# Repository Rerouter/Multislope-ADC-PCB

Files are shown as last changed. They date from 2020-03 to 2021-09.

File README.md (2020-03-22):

# Multislope-ADC-PCB
High Resolution Multi-slope ADC Kicad Files

Based on Kleinsteins original design as discussed on the EEVBlog Forum

https://www.eevblog.com/forum/metrology/diy-high-resolution-multi-slope-converter/

https://www.eevblog.com/forum/projects/multislope-design/

The goal of the project is to create a low cost multislope ADC with a useable resolution of 6.5 digits or higher.

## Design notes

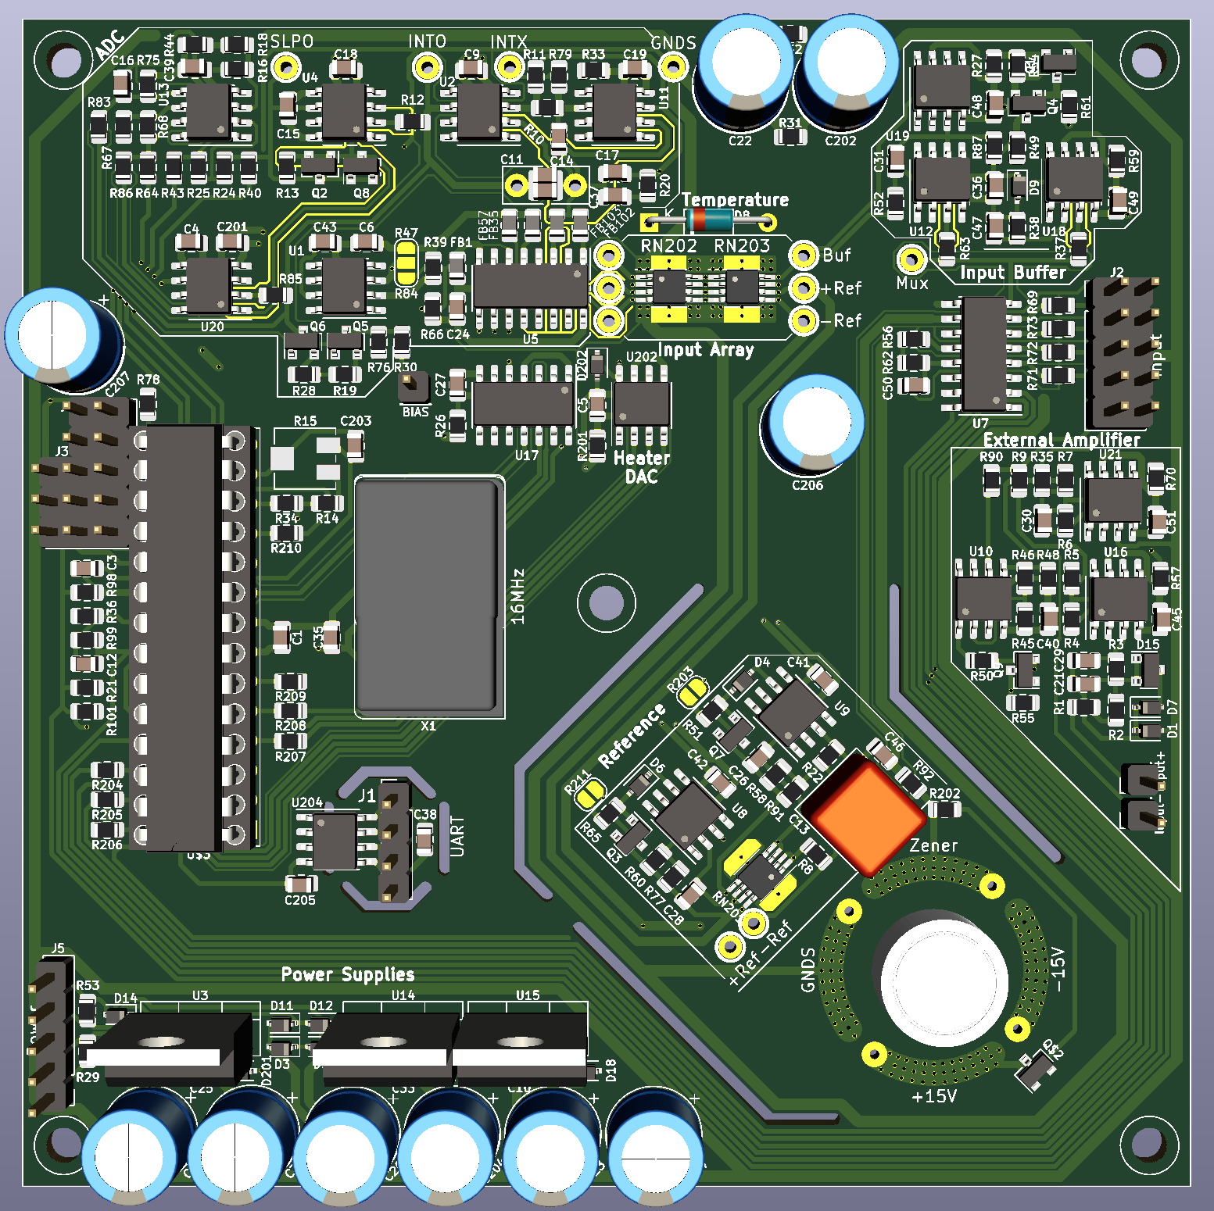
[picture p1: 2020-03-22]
ADC rev2-8.PNG

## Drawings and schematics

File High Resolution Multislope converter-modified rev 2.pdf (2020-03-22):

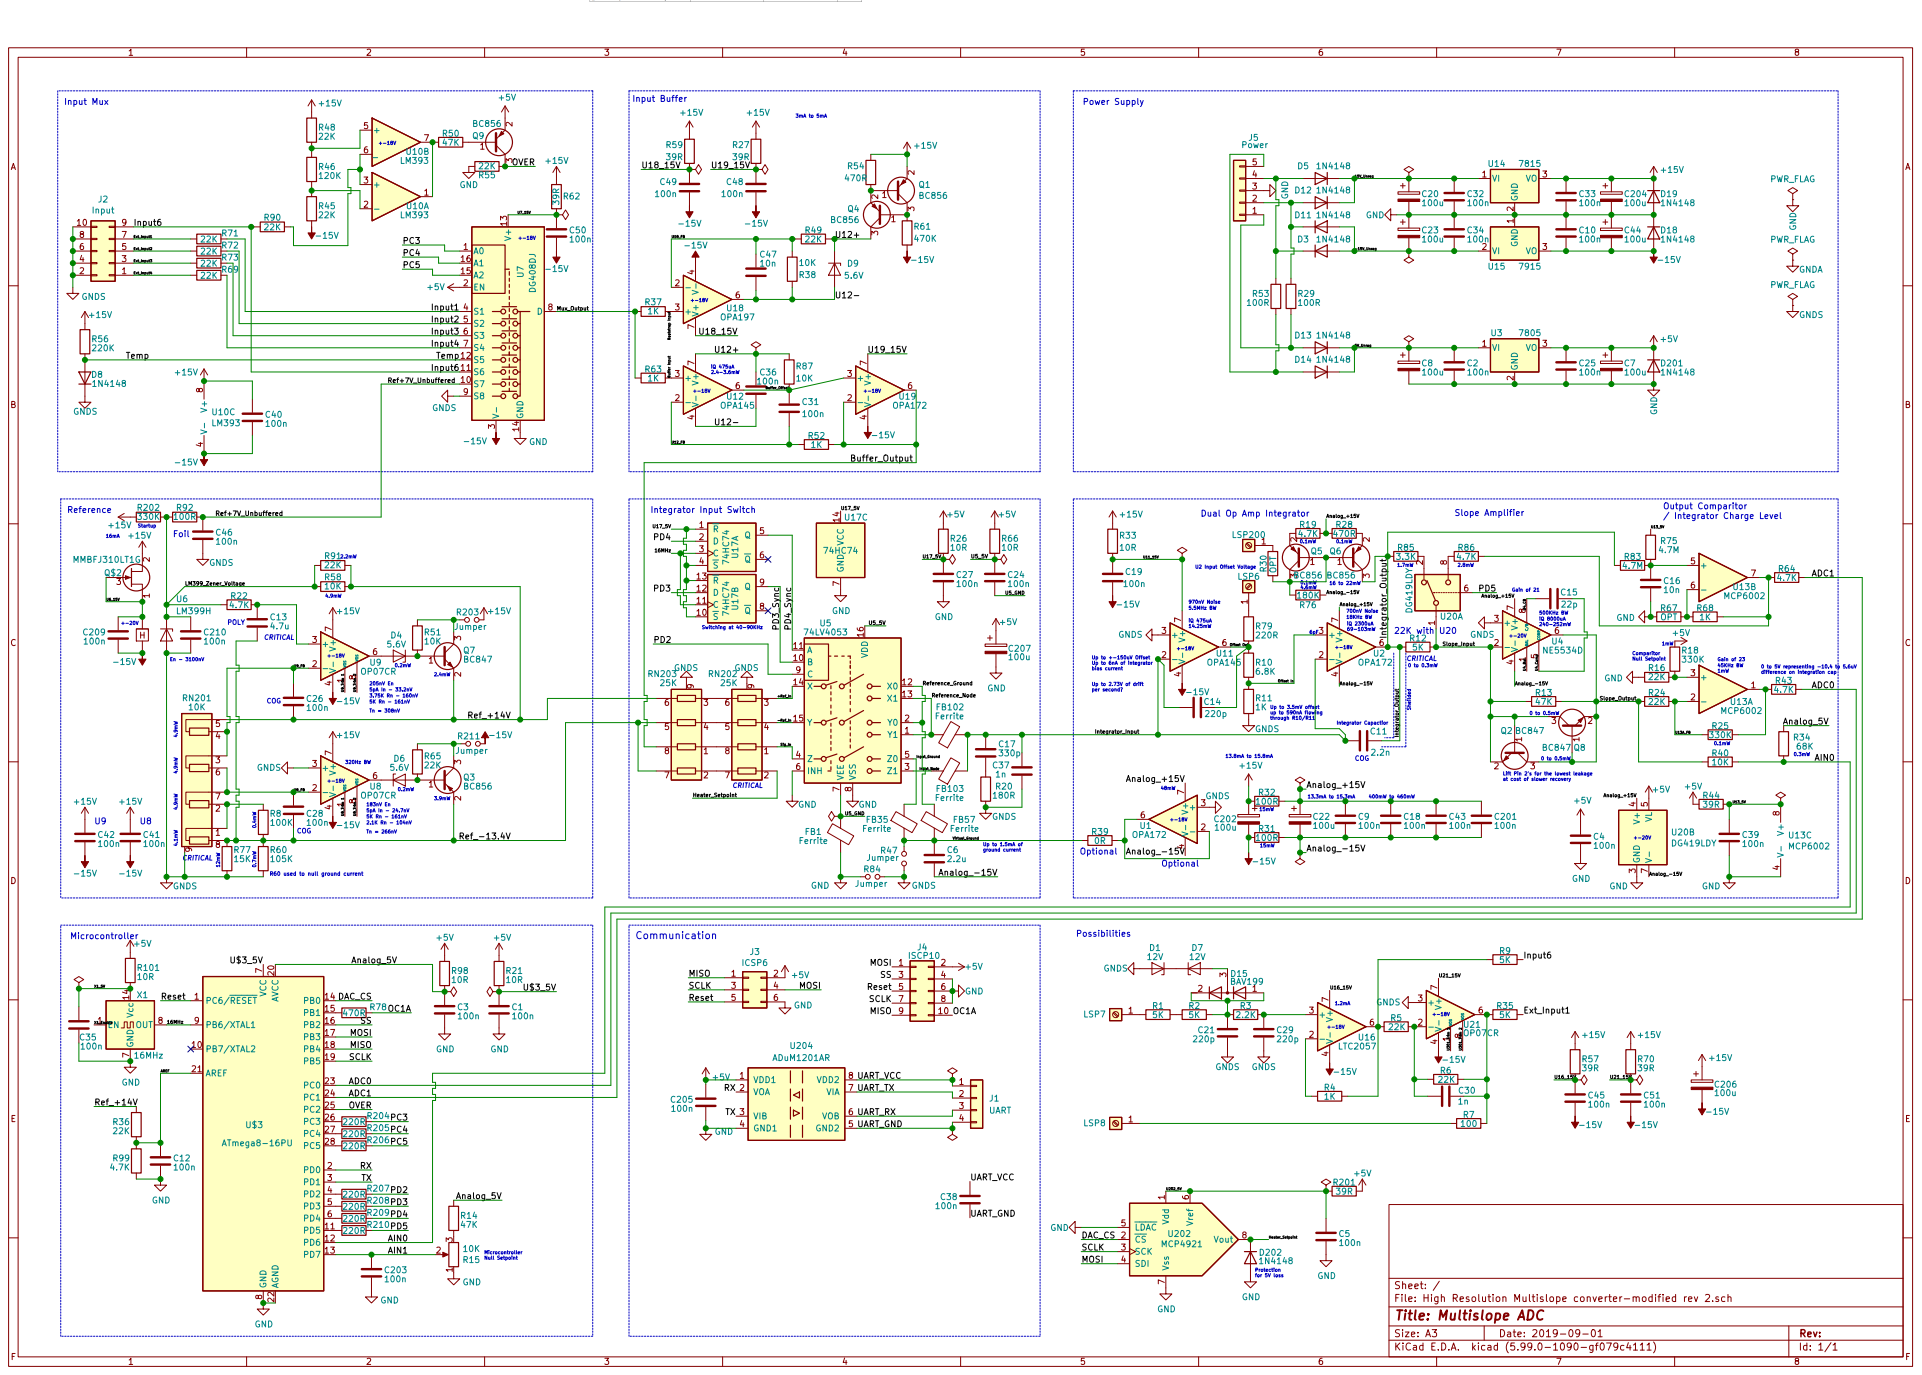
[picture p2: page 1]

U5_5V Bootstrap Input Buffer Input

/ Integrator Charge Level Switching at 40-90KHz COG

700nV Noise U2 Input Offset Voltage

Comparitor Null Setpoint 5pA In - 24.7nV

Lift Pin 2's for the lowest leakage

48mW Optional +-18V Up to 1.5mA of ground current

R60 used to null ground current 4.9mW 4.1mW

File: High Resolution Multislope converter-modified rev 2.sch Sheet: /
Id: 1/1 Title: Multislope ADC

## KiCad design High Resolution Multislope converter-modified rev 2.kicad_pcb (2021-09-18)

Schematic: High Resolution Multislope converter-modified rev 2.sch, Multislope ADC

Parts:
C1, C2, C3, C4, C5, C9, C10, C12, C18, C19, C24, C25, C26, C27, C28, C31, C32, C33, C34, C35, C36, C38, C39, C40, C41, C42, C43, C45, C46, C48, C49, C50, C51, C201, C203, C205, C209, C210: 100n; C_0805_2012Metric
C6: 2.2u; C_0805_2012Metric
C7, C8, C20, C22, C23, C44, C202, C204, C206, C207: 100u; CP_Radial_D8.0mm_P3.50mm
C11: 2.2n; C_Rect_L7.2mm_W3.0mm_P5.00mm_FKS2_FKP2_MKS2_MKP2
C13: 4.7u; C_Rect_L7.2mm_W7.2mm_P5.00mm_FKS2_FKP2_MKS2_MKP2
C14, C21, C29: 220p; C_0805_2012Metric
C15: 22p; C_0805_2012Metric
C16, C47: 10n; C_0805_2012Metric
C17: 330p; C_0805_2012Metric
C30, C37: 1n; C_0805_2012Metric
D1, D7: 12V; D_SOD-323
D3, D5, D8, D11, D12, D13, D14, D18, D19, D201, D202: 1N4148; D_SOD-323
D4, D6, D9: 5.6V; D_SOD-323
D15: BAV199; SOT-23; Manufacturer PArt Number BAV199-7-F; Digikey Part Number BAV199-FDICT-ND
FB1, FB35, FB57, FB102, FB103: Ferrite; L_0805_2012Metric; Manufacturer PArt Number MMZ2012Y152BT
J1: UART; PinHeader_1x04_P2.54mm_Vertical
J2: Input; PinHeader_2x05_P2.54mm_Vertical
J3: ICSP6; PinHeader_2x03_P2.54mm_Vertical
J4: ISCP10; PinHeader_2x05_P2.54mm_Vertical
J5: Power; PinHeader_1x05_P2.54mm_Vertical
LSP6: INTX; PinHeader_1x01_P2.54mm_Vertical
LSP7: Input+; PinHeader_1x01_P2.54mm_Vertical
LSP8: Input-; PinHeader_1x01_P2.54mm_Vertical
LSP200: BIAS; PinHeader_1x01_P2.54mm_Vertical
Q1, Q3, Q4, Q5, Q6, Q9: BC856; SOT-23; Manufacturer PArt Number BC857CLT1G
Q2, Q7, Q8: BC847; SOT-23; Manufacturer PArt Number BC847BLT3G
Q$2: MMBFJ310LT1G; SOT-23; Manufacturer PArt Number MMBFJ310LT1G
R1, R2, R9, R12, R35: 5K; R_0805_2012Metric
R3: 2.2K; R_0805_2012Metric
R4, R11, R37, R52, R63, R68: 1K; R_0805_2012Metric
R5, R6, R16, R24, R36, R45, R48, R49, R55, R65, R69, R71, R72, R73, R90, R91: 22K; R_0805_2012Metric
R7: 100; R_0805_2012Metric
R8: 100K; R_0805_2012Metric
R10: 6.8K; R_0805_2012Metric
R13, R14, R50: 47K; R_0805_2012Metric
R15: 10K; Potentiometer_Vishay_TS53YJ_Vertical
R18, R25, R202: 330K; R_0805_2012Metric
R19, R22, R43, R64, R86, R99: 4.7K; R_0805_2012Metric
R20: 180R; R_0805_2012Metric
R21, R26, R33, R66, R98, R101: 10R; R_0805_2012Metric
R27, R44, R57, R59, R62, R70, R201: 39R; R_0805_2012Metric
R28, R54, R78: 470R; R_0805_2012Metric
R29, R31, R32, R53, R92: 100R; R_0805_2012Metric
R30, R67: OPT; R_0805_2012Metric
R34: 68K; R_0805_2012Metric
R38, R40, R51, R58, R87: 10K; R_0805_2012Metric
R39: 0R; R_0805_2012Metric
R46: 120K; R_0805_2012Metric
R47, R84, R203, R211: Jumper; SolderJumper-2_P1.3mm_Open_RoundedPad1.0x1.5mm
R56: 220K; R_0805_2012Metric
R60: 105K; R_0805_2012Metric
R61: 470K; R_0805_2012Metric
R75, R83: 4.7M; R_0805_2012Metric
R76: 180K; R_0805_2012Metric
R77: 15K; R_0805_2012Metric
R79, R204, R205, R206, R207, R208, R209, R210: 220R; R_0805_2012Metric
R85: 3.3K; R_0805_2012Metric
RN201: 10K; MSOP-8-1EP_3x3mm_P0.65mm_EP1.73x1.85mm
RN202, RN203: 25K; MSOP-8-1EP_3x3mm_P0.65mm_EP1.73x1.85mm
U1, U2, U19: OPA172; SOIC-8_3.9x4.9mm_P1.27mm
U3: 7805; TO-220-3_Vertical
U4: NE5534D; SOIC-8_3.9x4.9mm_P1.27mm; Manufacturer PArt Number NE5534ADR2
U5: 74LV4053; SOIC-16_3.9x9.9mm_P1.27mm
U6: LM399H; TO-46-4; Manufacturer PArt Number LM399H#PBF
U7: DG408DJ; SOIC-16_3.9x9.9mm_P1.27mm; Manufacturer PArt Number DG408DY-T1-E3
U8, U9, U21: OP07CR; SOIC-8_3.9x4.9mm_P1.27mm
U10: LM393; SOIC-8_3.9x4.9mm_P1.27mm; Manufacturer PArt Number LM393DR2G
U11, U12: OPA145; SOIC-8_3.9x4.9mm_P1.27mm
U13: MCP6002; SOIC-8_3.9x4.9mm_P1.27mm; Manufacturer PArt Number MCP6002-E/SN
U14: 7815; TO-220-3_Vertical; Manufacturer PArt Number MC7815ACTG
U15: 7915; TO-220-3_Vertical; Manufacturer PArt Number MC7915CTG
U16: LTC2057; SOIC-8_3.9x4.9mm_P1.27mm; Manufacturer PArt Number LTC2057IS8#PBF
U17: 74HC74; SOIC-14_3.9x8.7mm_P1.27mm
U18: OPA197; SOIC-8_3.9x4.9mm_P1.27mm
U20: DG419LDY; SOIC-8_3.9x4.9mm_P1.27mm; Manufacturer PArt Number DG419DY-E3
U202: MCP4921; SOIC-8_3.9x4.9mm_P1.27mm; Manufacturer PArt Number MCP4821-E/SN
U204: ADuM1201AR; SOIC-8_3.9x4.9mm_P1.27mm; Manufacturer PArt Number ADUM1201ARZ
U$3: ATmega8-16PU; DIP-28_W7.62mm_Socket_LongPads
X1: 16MHz; Oscillator_DIP-14

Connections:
+5V: C4.1, C7.1, C25.1, C205.1, C207.1, D201.1 (K), J3.2, J4.2, Q9.2 (E), R18.1, R21.1, R26.1, R44.2, R66.1, R98.1, R101.1, R201.1, U3.3 (VO), U7.2 (EN), U20.5 (VL), U204.1 (VDD1)
+15V: C33.1, C40.1, C41.1, C42.1, C202.1, C204.1, C206.1, D19.1 (K), Q1.2 (E), Q$2.2 (S), R27.2, R32.2, R33.1, R48.1, R54.2, R56.1, R57.1, R59.2, R62.2, R70.1, R202.2, R203.2, U8.7 (V+), U9.7 (V+), U10.8, U14.3
-15V: C10.2, C19.2, C40.2, C41.2, C42.2, C44.2, C45.2, C48.2, C49.2, C50.2, C51.2, C202.2, C206.2, C209.2, D18.2 (A), R31.2, R45.2, R61.1, R211.2, U6.4 (-), U7.3 (V-), U8.4 (V-), U9.4 (V-), U10.4, U11.4 (V-), U15.3, U16.4 (V-), U18.4 (V-), U19.4 (V-), U21.4 (V-)
/5V_Unreg: C2.1, C8.1, D13.1 (K), D14.1 (K), U3.1 (VI)
/15V_Unreg: C20.1, C32.1, D5.1 (K), D12.1 (K), U14.1
/16MHz: U17.3 (C), U17.11 (C), U$3.9 (PB6/XTAL1), X1.8 (OUT)
/+Ref_In: RN202.3 (R3.1), U5.14 (X); also elsewhere on the board
/-15V_Unreg: C23.2, C34.2, D3.2 (A), D11.2 (A), U15.2
/-Ref_In: RN202.4 (R4.1), U5.15 (Y); also elsewhere on the board
/ADC0: R43.1, U$3.23 (PC0)
/ADC1: R64.1, U$3.24 (PC1)
/AIN0: R34.1, R40.1, U$3.12 (PD6)
/AIN1: C203.1, R15.2, U$3.13 (PD7)
/AREF: C12.1, R36.2, R99.1, U$3.21 (AREF)
/Analog_5V: C3.1, R14.1, R34.2, R98.2, U$3.20 (AVCC)
/Analog_+15V: C9.1, C18.1, C22.1, C43.1, C201.1, R19.1, R28.1, R32.1, U1.7 (V+), U2.7 (V+), U4.7 (V+), U20.4 (V+)
/Analog_-15V: C6.2, C9.2, C18.2, C22.2, C43.2, C201.2, R31.1, R76.2, U1.4 (V-), U2.4 (V-), U4.4 (V-), U20.7 (V-)
/Bootstrap Input: R37.1, U18.3 (+)
/Buffer Input: R63.1, U12.3 (+)
/Buffer_Offset: C31.2, R87.2, U12.6, U19.3 (+)
/Buffer_Output: R52.1, RN203.8 (R1.2), U19.2 (-), U19.6; also elsewhere on the board
/DAC_CS: U202.2 (~CS), U$3.14 (PB0)
/Ext_Input1: J2.7, R35.1, R71.2
/Ext_Input2: J2.5, R72.2
/Ext_Input3: J2.3, R73.2
/Ext_Input4: J2.1, R69.2
/Heater_Setpoint: D202.1 (K), RN202.2 (R2.1), U202.8 (Vout); also elsewhere on the board
/Input1: R71.1, U7.4 (S1)
/Input2: R72.1, U7.5 (S2)
/Input3: R73.1, U7.6 (S3)
/Input4: R69.1, U7.7 (S4)
/Input6: J2.9, R9.1, R90.2, U7.11 (S6)
/Input_Ground: FB35.1, U5.5 (Z0)
/Input_Node: FB103.1, U5.3 (Z1)
/Integrator_Input: C11.1, C14.1, C17.1, C37.1, FB102.2, FB103.2, U2.2 (-), U11.2 (-); also elsewhere on the board
/Integrator_Output: C11.2, Q6.3 (C), R12.2, R83.2, R85.2, U2.6; also elsewhere on the board
/LM399_Zener_Voltage: C210.1, R22.2, R58.2, R91.2, R92.2, R202.1, U6.1 (K)
/MISO: J3.1, J4.9, U$3.18 (PB4)
/MOSI: J3.4, J4.1, U202.4 (SDI), U$3.17 (PB3)
/Mux_Output: R37.2, R63.2, U7.8 (D); also elsewhere on the board
/OC1A: J4.10, R78.1
/OVER: Q9.3 (C), R55.2, U$3.25 (PC2)
/Offset In: R10.2, R11.2, U2.3 (+)
/Offset Out: C14.2, R10.1, R79.2, U11.6
/PC3: R204.1, U7.1 (A0)
/PC4: R205.1, U7.16 (A1)
/PC5: R206.1, U7.15 (A2)
/PD2: R207.1, U5.9 (C)
/PD3: R208.1, U17.12 (D)
/PD3_Sync: U5.10 (B), U17.9 (Q)
/PD4: R209.1, U17.2 (D)
/PD4_Sync: U5.11 (A), U17.5 (Q)
/PD5: R210.1, U20.6
/RX: U204.2 (VOA), U$3.2 (PD0)
/Ref+7V_Unbuffered: C46.1, R92.1, U7.10 (S7)
/Ref_+14V: C26.2, Q7.2 (E), R36.1, R58.1, R91.1, RN201.5 (R4.2), RN203.6 (R3.2); also elsewhere on the board
/Ref_-13.4V: C13.2, C28.2, Q3.2 (E), R8.2, R60.1, R77.1, RN201.8 (R1.1), RN203.5 (R4.2), RN203.7 (R2.2); also elsewhere on the board
/Reference_Ground: FB57.1, U5.2 (Y0), U5.12 (X0)
/Reference_Node: FB102.1, U5.1 (Y1), U5.13 (X1)
/Reset: J3.5, J4.5, U$3.1 (PC6/~RESET)
/SCLK: J3.3, J4.7, U202.3 (SCK), U$3.19 (PB5)
/SS: J4.3, U$3.16 (PB2)
/Sig_In: RN202.1 (R1.1), U5.4 (Z); also elsewhere on the board
/Slope_Input: Q2.1 (B), Q2.2 (E), Q8.3 (C), R12.1, R13.2, U4.2 (-), U20.1
/Slope_Output: Q2.3 (C), Q8.1 (B), Q8.2 (E), R13.1, R24.2, R40.2, U4.6; also elsewhere on the board
/TX: U204.3 (VIB), U$3.3 (PD1)
/Temp: D8.2 (A), R56.2, U7.12 (S5)
/U4_Bal: U4.1 (BAL)
/U4_CB: C15.1, U4.8 (C/B)
/U4_Comp: C15.2, U4.5 (COMP)
/U5_5V: C24.1, R66.2, U5.16 (VDD)
/U5_GND: C24.2, FB1.1, U5.7 (VEE)
/U6_15V: C209.1, Q$2.1 (D), Q$2.3 (G), U6.3 (+)
/U7_15V: C50.1, R62.1, U7.13 (V+)
/U8_FB: C28.1, RN201.6 (R3.1), RN201.7 (R2.2), U8.2 (-); also elsewhere on the board
/U8_Trim 1: U8.1 (VOS)
/U8_Trim 2: U8.8 (VOS)
/U9_FB: C26.1, RN201.3 (R3.2), RN201.4 (R4.1), U9.2 (-); also elsewhere on the board
/U9_Trim 1: U9.1 (VOS)
/U9_Trim 2: U9.8 (VOS)
/U11_15V: C19.1, R33.2, U11.7 (V+)
/U12+: C36.1, D9.1 (K), Q4.3 (C), R49.2, R87.1, U12.7 (V+)
/U12-: C36.2, C47.2, D9.2 (A), R38.1, U12.4 (V-), U18.6
/U12_FB: C31.1, R52.2, U12.2 (-)
/U13A_FB: R24.1, R25.2, U13.2
/U13_5V: C39.1, R44.1, R75.2, U13.8
/U16_15V: C45.1, R57.2, U16.7 (V+)
/U17_5V: C27.1, R26.2, U17.1 (~R), U17.4 (~S), U17.10 (~S), U17.13 (~R), U17.14 (VCC)
/U18_15V: C49.1, R59.1, U18.7 (V+)
/U18_FB: C47.1, R38.2, R49.1, U18.2 (-)
/U19_15V: C48.1, R27.1, U19.7 (V+)
/U21_15V: C51.1, R70.2, U21.7 (V+)
/U202_5V: C5.1, R201.2, U202.1 (Vdd), U202.6 (Vref)
/U301_Trim 1: U21.1 (VOS)
/U301_Trim 2: U21.8 (VOS)
/U$3_5V: C1.1, R21.2, U$3.7 (VCC)
/UART_GND: C38.2, J1.4, U204.5 (GND2)
/UART_RX: J1.3, U204.6 (VOB)
/UART_TX: J1.2, U204.7 (VIA)
/UART_VCC: C38.1, J1.1, U204.8 (VDD2)
/Virtual_Ground: C6.1, FB35.2, FB57.2, R39.2, R47.1
/X1_5V: C35.1, R101.2, X1.14 (Vcc)
/X1_Enable: X1.1 (EN)
GND: C1.2, C2.2, C3.2, C4.2, C5.2, C7.2, C8.2, C10.1, C12.2, C16.2, C20.2, C23.1, C25.2, C27.2, C32.2, C33.2, C34.1, C35.2, C39.2, C44.1, C203.2, C204.2, C205.2, C207.2, D18.1 (K), D19.2 (A), D201.2 (A), D202.2 (A), FB1.2, J3.6, J4.4, J4.6, J4.8, J5.3, R15.1, R16.1, R55.1, R67.2, R84.1, R99.2, U3.2 (GND), U5.6 (INH), U5.8 (VSS), U7.14 (GND), U13.4, U14.2, U15.1, U17.7 (GND), U20.3 (GND), U202.5 (~LDAC), U202.7 (Vss), U204.4 (GND1), U$3.8 (GND), U$3.22 (AGND), X1.7 (GND)
GNDS: C21.2, C29.2, C37.2, C46.2, C210.2, D1.2 (A), D8.1 (K), J2.2, J2.4, J2.6, J2.8, J2.10, R11.1, R20.2, R47.2, R60.2, R77.2, R84.2, RN201.9 (Pad), RN202.9 (Pad), RN203.9 (Pad), U1.3 (+), U4.3 (+), U6.2 (A), U7.9 (S8), U8.3 (+), U11.3 (+), U21.3 (+); also elsewhere on the board
unnamed: C13.1, R22.1, U9.3 (+)
unnamed: C16.1, R75.1, R83.1, U13.5
unnamed: C17.2, R20.1
unnamed: C21.1, D15.1 (A), D15.2 (K), R2.1, R3.2
unnamed: C29.1, R3.1, U16.3 (+)
unnamed: C30.1, R5.2, R6.1, U21.2 (-)
unnamed: C30.2, R6.2, R7.1, R35.2, U21.6
unnamed: D1.1 (K), D7.1 (K)
unnamed: D3.1 (K), D5.2 (A), J5.4, R53.1
unnamed: D4.1 (K), Q7.1 (B), R51.2
unnamed: D4.2 (A), U9.6
unnamed: D6.1 (K), U8.6
unnamed: D6.2 (A), Q3.1 (B), R65.2
unnamed: D11.1 (K), D12.2 (A), J5.2, R29.1
unnamed: D13.2 (A), J5.1, R29.2
unnamed: D14.2 (A), J5.5, R53.2
unnamed: D7.2 (A), D15.3 (common)
unnamed: LSP6.1, R79.1
unnamed: LSP7.1, R1.2
unnamed: LSP8.1, R7.2
unnamed: LSP200.1, R30.2
unnamed: Q1.1 (B), Q4.2 (E), R54.1
unnamed: Q1.3 (C), Q4.1 (B), R61.2
unnamed: Q3.3 (C), R65.1, R211.1
unnamed: Q5.1 (B), Q5.3 (C), Q6.1 (B), R30.1, R76.1
unnamed: Q5.2 (E), R19.2
unnamed: Q6.2 (E), R28.2
unnamed: Q7.3 (C), R51.1, R203.1
unnamed: Q9.1 (B), R50.1
unnamed: R1.1, R2.2
unnamed: R4.1, R5.1, R9.2, U16.6
unnamed: R4.2, U16.2 (-)
unnamed 137: R8.1, RN201.1 (R1.2), RN201.2 (R2.1); also elsewhere on the board
unnamed: R14.2, R15.3
unnamed: R16.2, R18.2, U13.3
unnamed: R25.1, R43.2, U13.1
unnamed: R39.1, U1.2 (-), U1.6
unnamed: R45.1, R46.2, U10.2
unnamed: R46.1, R48.2, U10.5
unnamed: R50.2, U10.1, U10.7
unnamed: R64.2, R68.1, R86.1, U13.7
unnamed: R67.1, R68.2, U13.6
unnamed: R78.2, U$3.15 (PB1)
unnamed: R85.1, U20.2
unnamed: R86.2, U20.8
unnamed: R90.1, U10.3, U10.6
unnamed: R204.2, U$3.26 (PC3)
unnamed: R205.2, U$3.27 (PC4)
unnamed: R206.2, U$3.28 (PC5)
unnamed: R207.2, U$3.4 (PD2)
unnamed: R208.2, U$3.5 (PD3)
unnamed: R209.2, U$3.6 (PD4)
unnamed: R210.2, U$3.11 (PD5)
unnamed 158: RN202.5 (R4.2), RN203.4 (R4.1); also elsewhere on the board
unnamed 159: RN202.6 (R3.2), RN203.3 (R3.1); also elsewhere on the board
unnamed 160: RN202.7 (R2.2), RN203.2 (R2.1); also elsewhere on the board
unnamed 161: RN202.8 (R1.2), RN203.1 (R1.1); also elsewhere on the board

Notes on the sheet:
Input Mux
Microcontroller
16mA
Reference
+-20V
Startup
En - 3100nV
Foil
4.9mW
4.1mW
CRITICAL
12mW
POLY
0.4mW
0.7mW
COG
R60 used to null ground current
+-18V
320Hz BW
2.2mW
183nV En
5pA In - 24.7nV
5K Rn - 161nV
2.1K Rn - 104nV
Tn = 266nV
205nV En
5pA In - 33.2nV
3.75K Rn - 160nV
Tn = 308nV
OPA07 - <500Hz
0.2mW
2.4mW
3.9mW
Microcontroller Null Setpoint
Input Buffer
Communication
Integrator Input Switch
OPA145 - 5.5MHz
Switching at 40-90KHz
iQ 475uA 2.4-3.6mW

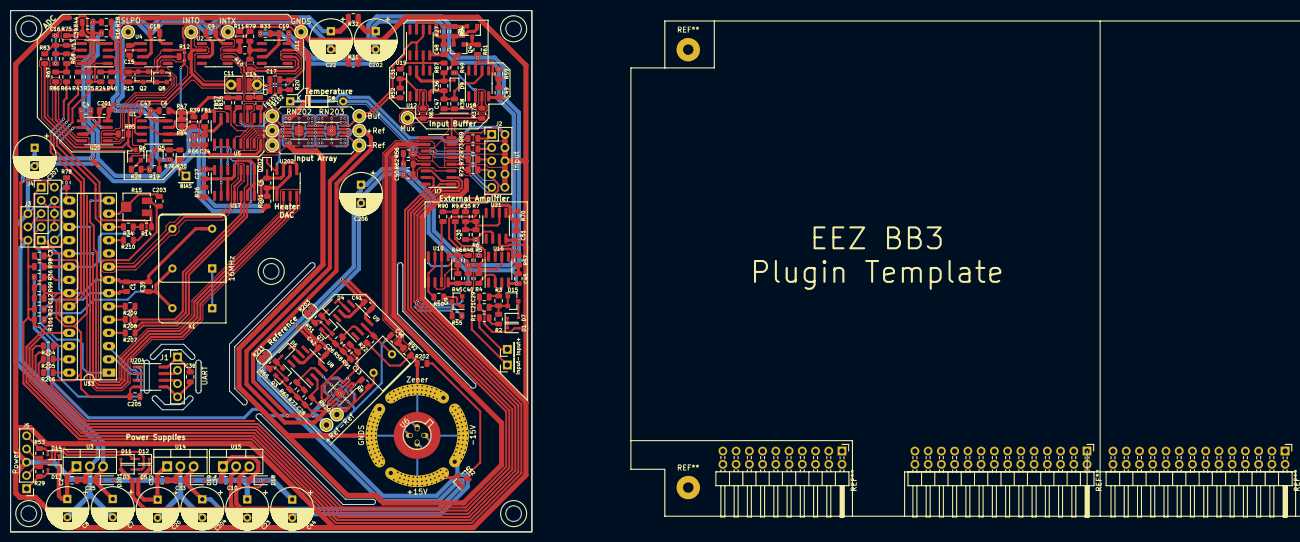
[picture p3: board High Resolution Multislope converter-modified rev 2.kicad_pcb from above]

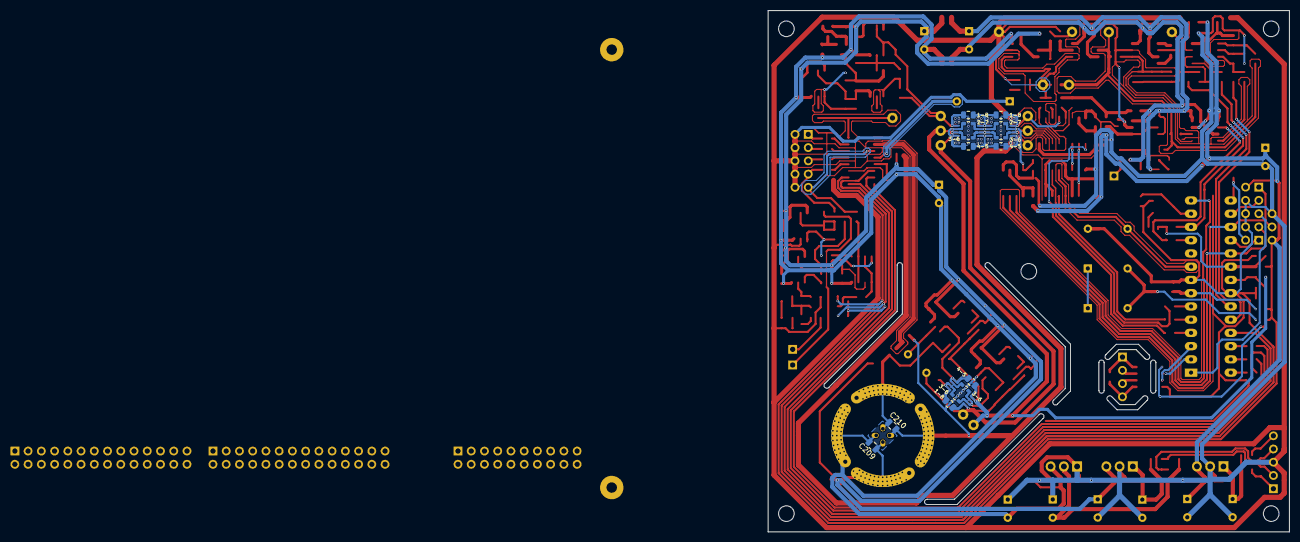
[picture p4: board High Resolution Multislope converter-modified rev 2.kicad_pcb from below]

Board: 2 copper layers, 100.0 x 100.0 mm, 250 parts (14 on the bottom side), 154 nets.

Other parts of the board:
1-8, 4-5: 10K; R_0805_2012Metric
1-8#2, 1-8#3, 2-7, 2-7#2, 3-6, 3-6#2, 3-6#3, 3-6#4, 4-5#2, 4-5#3: 20K; R_0805_2012Metric
+Ref: Pin_Header_Straight_1x01_Pitch2.54mm
+Ref#2, +Ref#3: Pin_Header_Straight_1x01_Pitch2.54mm
-Ref: Pin_Header_Straight_1x01_Pitch2.54mm
-Ref#2, -Ref#3: Pin_Header_Straight_1x01_Pitch2.54mm
Buf: Pin_Header_Straight_1x01_Pitch2.54mm
Buf#2: Pin_Header_Straight_1x01_Pitch2.54mm
C11#2: 2.2n; C_Rect_L7.2mm_W3.0mm_P5.00mm_FKS2_FKP2_MKS2_MKP2
GNDS: Pin_Header_Straight_1x01_Pitch2.54mm
INTO: Pin_Header_Straight_1x01_Pitch2.54mm
Mux: Pin_Header_Straight_1x01_Pitch2.54mm
SLPO: Pin_Header_Straight_1x01_Pitch2.54mm

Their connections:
/+Ref_In: 3-6#3.1, +Ref#3.1; also elsewhere on the board
/-Ref_In: 4-5#3.1, -Ref#3.1; also elsewhere on the board
/Buffer_Output: 1-8#2.2, Buf.1; also elsewhere on the board
/Heater_Setpoint: 2-7#2.1; also elsewhere on the board
/Integrator_Input: C11#2.1; also elsewhere on the board
/Integrator_Output: C11#2.2, INTO.1; also elsewhere on the board
/Mux_Output: Mux.1; also elsewhere on the board
/Ref_+14V: 3-6#4.1, 4-5.2, +Ref.1, +Ref#2.1; also elsewhere on the board
/Ref_-13.4V: 1-8.2, 2-7.2, 4-5#2.2, -Ref.1, -Ref#2.1; also elsewhere on the board
/Sig_In: 1-8#3.1, Buf#2.1; also elsewhere on the board
/Slope_Output: SLPO.1; also elsewhere on the board
/U8_FB: 3-6.2, 3-6#2.1; also elsewhere on the board
/U9_FB: 3-6#2.2, 4-5.1; also elsewhere on the board
GNDS: GNDS.1; also elsewhere on the board
unnamed 137: 1-8.1, 3-6.1; also elsewhere on the board
unnamed 158: 4-5#2.1, 4-5#3.2; also elsewhere on the board
unnamed 159: 3-6#3.2, 3-6#4.2; also elsewhere on the board
unnamed 160: 2-7.1, 2-7#2.2; also elsewhere on the board
unnamed 161: 1-8#2.1, 1-8#3.2; also elsewhere on the board

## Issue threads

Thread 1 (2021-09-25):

Errors in rev 2 from 22 Mar 2020

Fuchks, 2021-09-25:
BOM/PCB:
C26/28 (/31/46/210 [209/48/49/50/... ?]) 100nF C0G not awailable in 0805, only in 1206 (C0G preferred in signal path and for critical blocking), alternative is paralleled 2x 47nF in 0805 (as bodge on top of each other)
(C46 marked as foil in schematic -> C0G
all C0G should be marked in BOM/Schematic)

BOM (see [used BOM@mouser](https://www.mouser.com/ProjectManager/ProjectDetail.aspx?AccessID=e76d4bfca5)) :
U3: has to be ATMEGA48(P)A
R1, R2, R9, R12, R35: 5k -> 4.99k (E96)
U7: has to be DG408DY
U5: has to be SN74LV4053AD(R)
X1: 12MHz (preferred, 16MHz possible -> needs FW change)
R7: 100R (is 100)

PCB:
DRC gave me some errors, which I corrected for fabrication of PCB @ JLCPCB
Zener TP is underneath C13
Programming headers 10P: standard programming plug does not fit (C207 to close)
Programming headers 10/6P: No markings visible for Pin1 (if both are populated the standard programming plugs do not fit)

Remarks
Removed differential frontend (LTC2057 & OP07), it happily oscillated
Did not populate U20, U1, C37, U202, Q2
ADC0 connection had to be swapped to ADC1 due to changes in revs by Kleinstein -> can be addressed in FW

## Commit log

2020-03-22 Initial File Sync
    [High Resolution Multislope converter-modified rev 2.kicad_pcb, High Resolution Multislope converter-modified rev 2.sch]
2020-03-23 Added silk screen descriptions
    All test points and through hole points labeled on front and back
    Added test points near to the reference to make it easier to add other references.
    [High Resolution Multislope converter-modified rev 2.kicad_pcb, High Resolution Multislope converter-modified rev 2.sch, High Resolution Multislope converter-mo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]
2021-09-18 Fix up errors in first fix,
    [High Resolution Multislope converter-modified rev 2.kicad_pcb]
